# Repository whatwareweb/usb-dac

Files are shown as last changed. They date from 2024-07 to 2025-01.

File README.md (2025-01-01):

# usb-dac

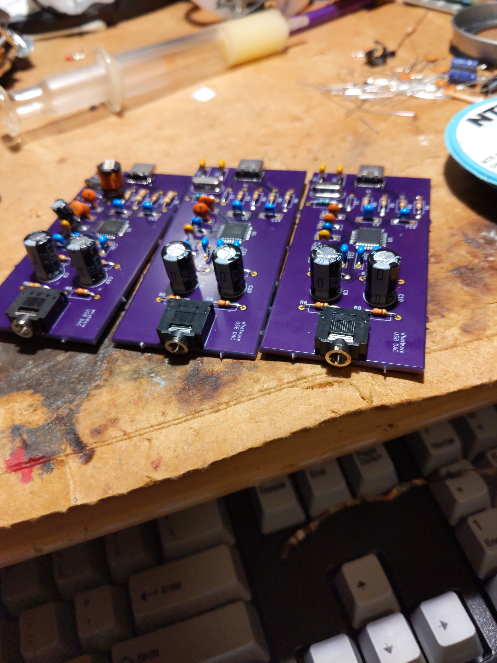
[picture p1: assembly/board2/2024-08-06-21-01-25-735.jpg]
photos of assembled boards


USB DAC based on TI PCM2912A IC

This design is tested and working, I use it as my daily driver DAC

## pcb fabrication
I ordered my pcbs from OSHpark, the project link is here for a 1-click order that is already configured and will work well https://oshpark.com/shared_projects/iy0FjLmS

## performance tweaking
This DAC has been designed with good low-frequency response in mind, large output capacitors are used to ensure very low frequencies can be reproduced

To adjust high-frequency response, C4 and C5 can be decreased to allow higher-frequency sounds to make it to the output. Too high of a capacitance for either of these will lead to a muffled sound

C9 and C10 are the output capacitors, the Rubycon model listed in the BOM does very well for the price but they can be swapped out for any higher quality electrolytic capacitor with the same lead spacing. to increase LF response make these a larger value, to decrease make them a smaller value. I just used these as I had like 70 of them spare from another project

## assembly
Check the assembly directory for assembly pictures

This board design is tested and working, but if you would like any help you can open a github issue and I'll try my best (no i will most likely not give you one for free, sorry)

During assembly it is very helpful to open the board view in KiCad to see the component values and the BOM

This board has been designed with easy assembly in mind, there are only 2 SMD parts which you could get assembled for you at a PCB assembly service, the rest of the parts are through-hole and very easy to solder DIY.

## parts
The parts in the BOM can all be purchased at Mouser electronics (DigiKey probably has them too, I didn't check)

I just went with the cheapest option of the rated component value with a minimum voltage rating of 5v, so if you need to get components from some other supplier you can do that as well and it will probably work, just make sure to double-check the lead spacing for the capacitors, inductors, etc

## bom
To export the BOM, open the schematic in Kicad, and click the BOM icon in the toolbar, from there you can copy/paste or export

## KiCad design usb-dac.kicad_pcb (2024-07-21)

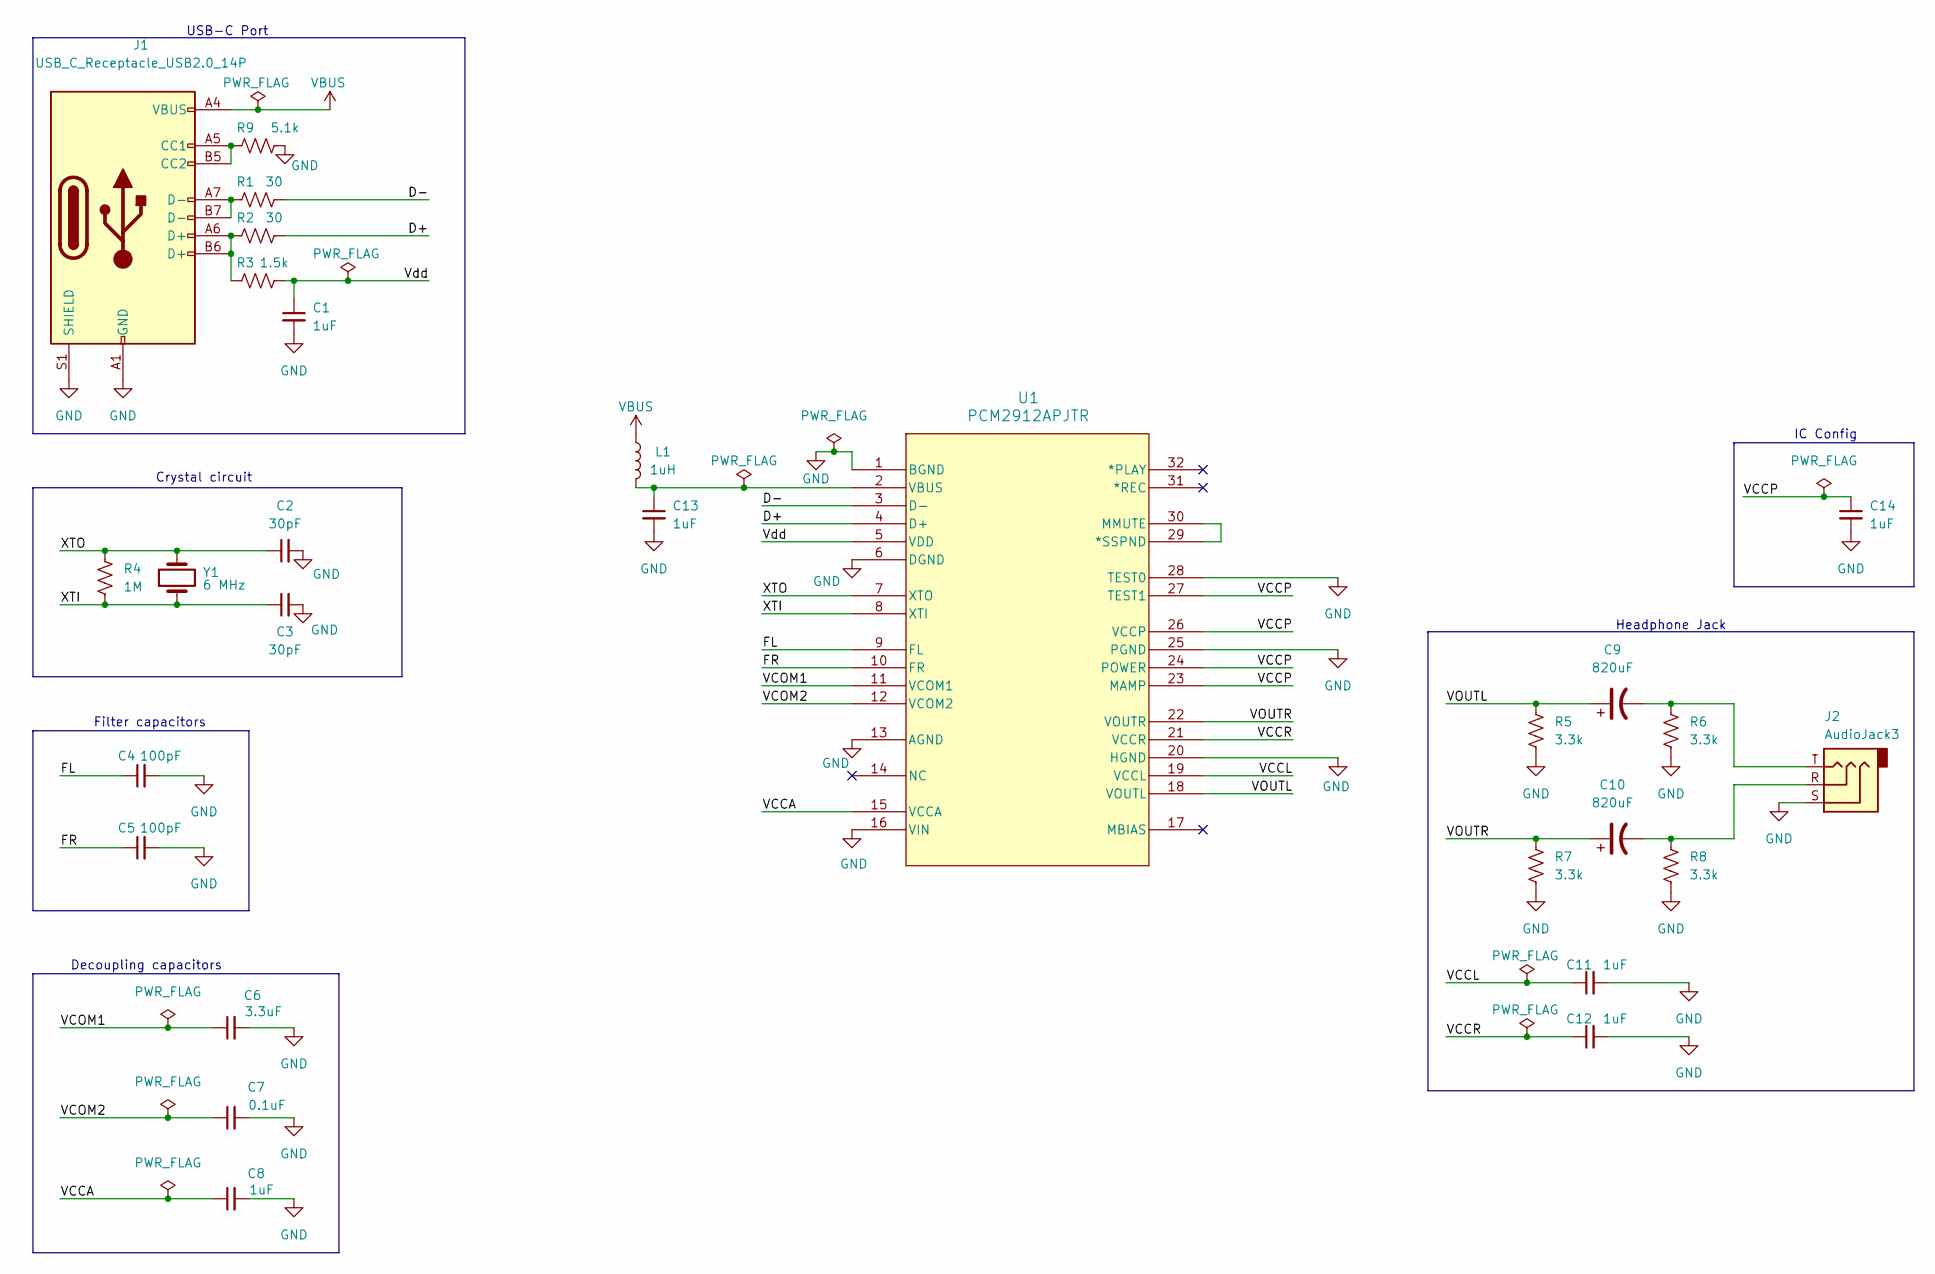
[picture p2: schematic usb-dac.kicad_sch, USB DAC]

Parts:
C1, C8, C11, C12, C13, C14: 1uF; C_Rect_L7.0mm_W2.0mm_P5.00mm; Mfr. # FG28X7R1E105KRT00
C2, C3: 30pF; C_Rect_L7.0mm_W2.0mm_P5.00mm; Mfr. # K300J10C0GF5UH5
C4, C5: 100pF; C_Rect_L7.0mm_W2.0mm_P5.00mm; Mfr. # XR501101K040HAND5P
C6: 3.3uF; C_Rect_L7.0mm_W2.0mm_P5.00mm; Mfr. # FA24X7R1E335KRU06
C7: 0.1uF; C_Rect_L7.0mm_W2.0mm_P5.00mm; Mfr. # K104K10X7RF5UH5
C9, C10: 820uF; CP_Radial_D8.0mm_P3.50mm; Mfr. # 6.3ZLH820MEFC8X11.5
J1: USB_C_Receptacle_USB2.0_14P; USB_C_Receptacle_GCT_USB4105-xx-A_16P_TopMnt_Horizontal; Mfr. # USB4085
J2: AudioJack3; Jack_3.5mm_CUI_SJ1-3523N_Horizontal; Mfr. # SJ1-3523N
L1: 1uH; L_Axial_L5.3mm_D2.2mm_P7.62mm_Horizontal_Vishay_IM-1; Mfr. # AICC-02-1R0M-T
R1, R2: 30; R_Axial_DIN0207_L6.3mm_D2.5mm_P10.16mm_Horizontal; Mfr. # CF14JT30R0
R3: 1.5k; R_Axial_DIN0207_L6.3mm_D2.5mm_P10.16mm_Horizontal; Mfr. # CFR-12JB-52-1K5
R4: 1M; R_Axial_DIN0207_L6.3mm_D2.5mm_P10.16mm_Horizontal; Mfr. # RNF18FTD1M00
R5, R6, R7, R8: 3.3k; R_Axial_DIN0207_L6.3mm_D2.5mm_P10.16mm_Horizontal; Mfr. # CFM14JT3K30
R9: 5.1k; R_Axial_DIN0207_L6.3mm_D2.5mm_P10.16mm_Horizontal; Mfr. # CF18JT5K10
U1: PCM2912APJTR; TQFP-32_7x7mm_P0.8mm; Mfr. # PCM2912APJTR
Y1: 6 MHz; Crystal_HC49-U_Vertical; Mfr. # ATS060

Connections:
/D+: R2.2, U1.4 (D+)
/D-: R1.2, U1.3 (D-)
/FL: C4.1, U1.9 (FL)
/FR: C5.1, U1.10 (FR)
/VCCA: C8.1, U1.15 (VCCA)
/VCCL: C11.1, U1.19 (VCCL)
/VCCP: C14.1, U1.23 (MAMP), U1.24 (POWER), U1.26 (VCCP), U1.27 (TEST1)
/VCCR: C12.1, U1.21 (VCCR)
/VCOM1: C6.1, U1.11 (VCOM1)
/VCOM2: C7.1, U1.12 (VCOM2)
/VOUTL: C9.1, R5.1, U1.18 (VOUTL)
/VOUTR: C10.1, R7.1, U1.22 (VOUTR)
/Vdd: C1.1, R3.2, U1.5 (VDD)
/XTI: C3.1, R4.2, U1.8 (XTI), Y1.1
/XTO: C2.1, R4.1, U1.7 (XTO), Y1.2
GND: C1.2, C2.2, C3.2, C4.2, C5.2, C6.2, C7.2, C8.2, C11.2, C12.2, C13.2, C14.2, J1.A1 (GND), J1.A12 (GND), J1.B1 (GND), J1.B12 (GND), J1.S1 (SHIELD), J2.S, R5.2, R6.2, R7.2, R8.2, R9.2, U1.1 (BGND), U1.6 (DGND), U1.13 (AGND), U1.16 (VIN), U1.20 (HGND), U1.25 (PGND), U1.28 (TEST0)
unnamed: C9.2, J2.T, R6.1
unnamed: C10.2, J2.R, R8.1
unnamed: J1.A5 (CC1), J1.B5 (CC2), R9.1
unnamed: J1.A6 (D+), J1.B6 (D+), R2.1, R3.1
unnamed: J1.A7 (D-), J1.B7 (D-), R1.1
unnamed: U1.29 (*SSPND), U1.30 (MMUTE)
unnamed: C13.1, L1.2, U1.2 (VBUS)
VBUS: J1.A4 (VBUS), J1.A9 (VBUS), J1.B4 (VBUS), J1.B9 (VBUS), L1.1

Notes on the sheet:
Filter capacitors
Headphone Jack
USB-C Port
Crystal circuit
Decoupling capacitors
IC Config

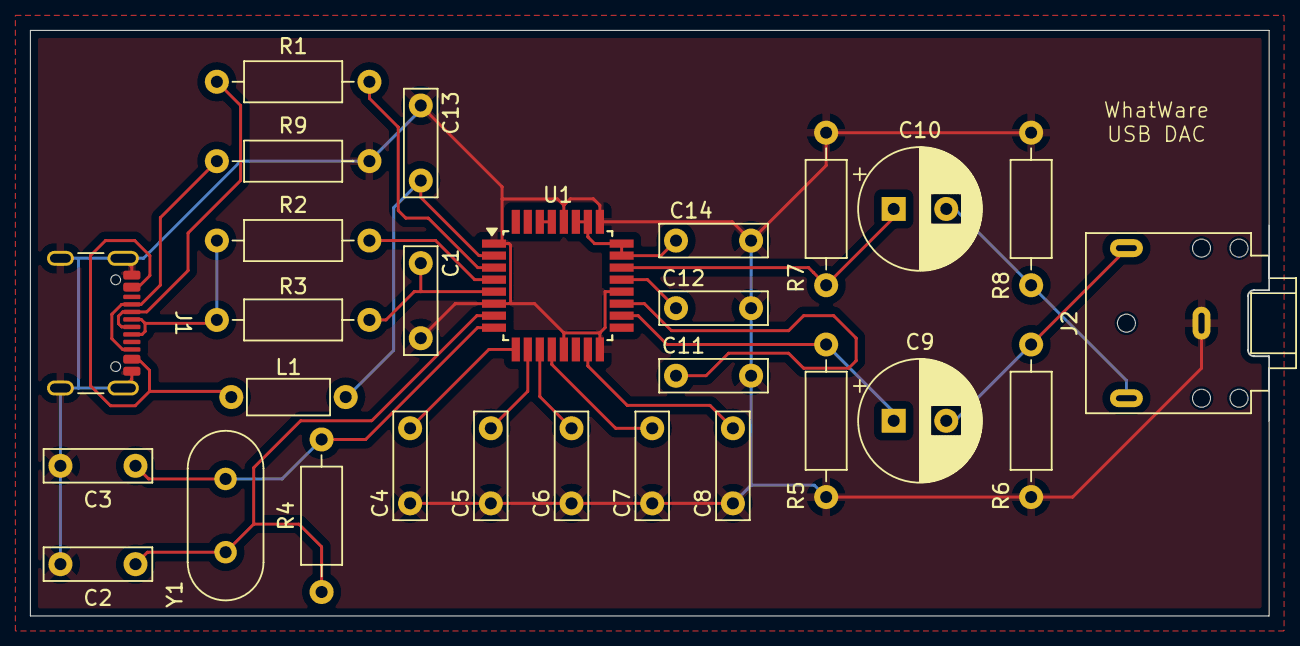
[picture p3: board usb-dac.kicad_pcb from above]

Board: 2 copper layers, 82.5 x 39.0 mm, 28 parts (0 on the bottom side), 24 nets.

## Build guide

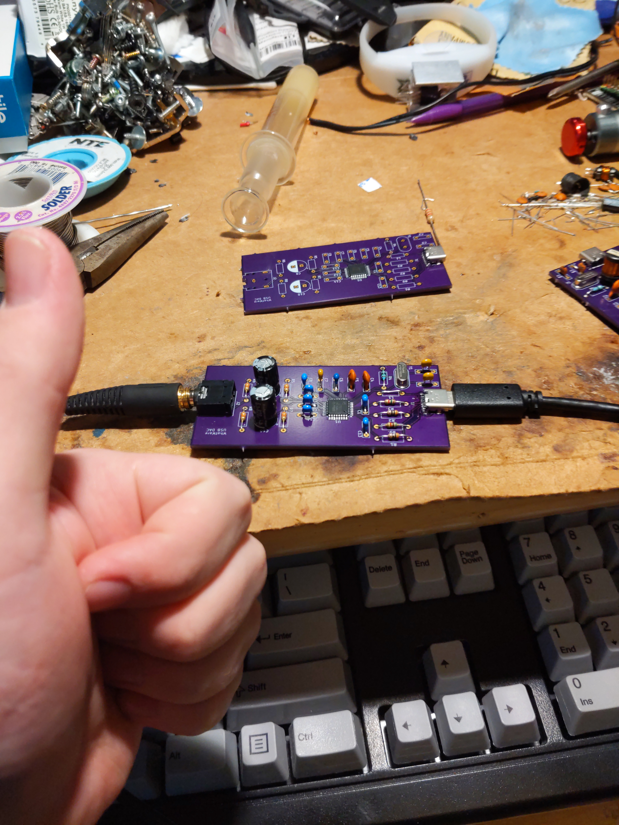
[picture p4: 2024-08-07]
assembly/board1/2024-08-06-19-01-29-325.jpg

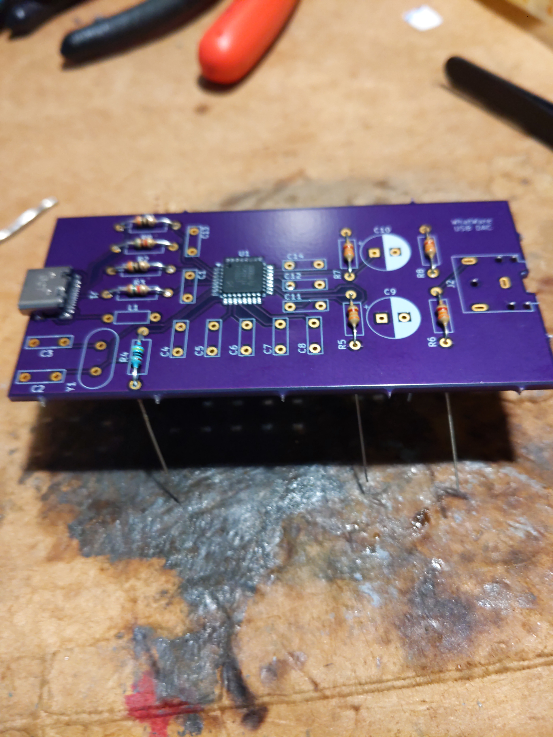
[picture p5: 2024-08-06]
assembly/board1/2024-08-06-17-47-50-258.jpg

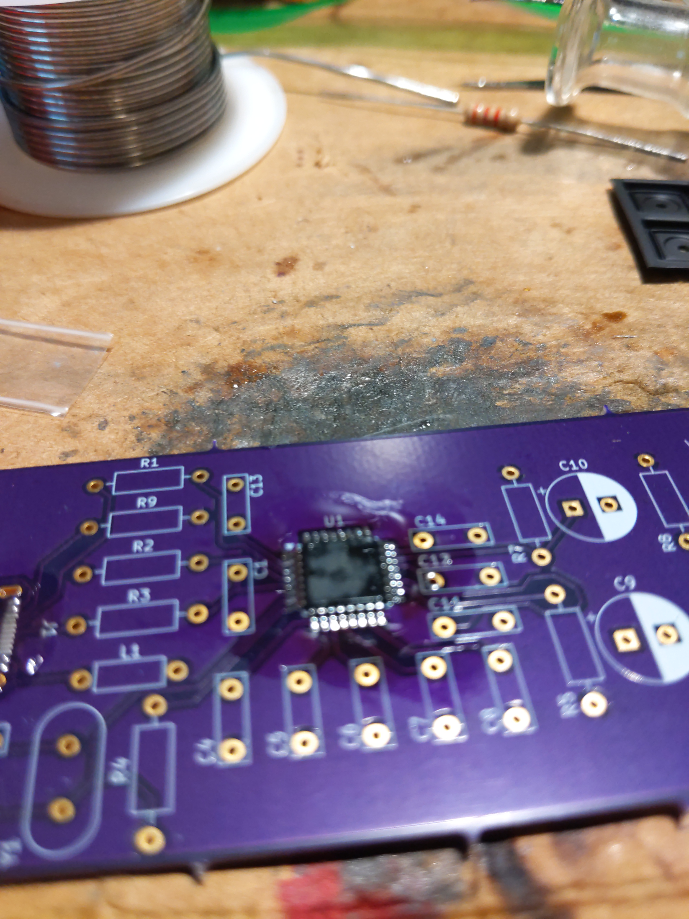
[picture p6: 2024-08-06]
assembly/board1/2024-08-06-16-56-17-795.jpg

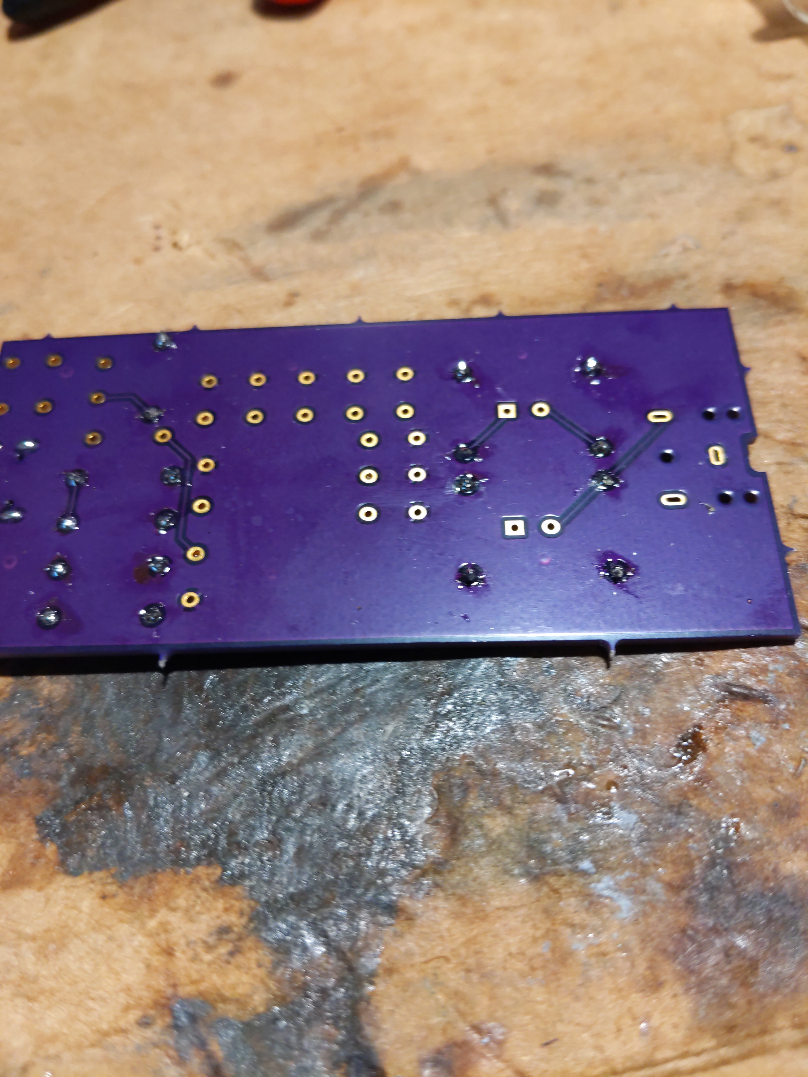
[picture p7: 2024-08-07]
assembly/board1/2024-08-06-17-56-30-761.jpg

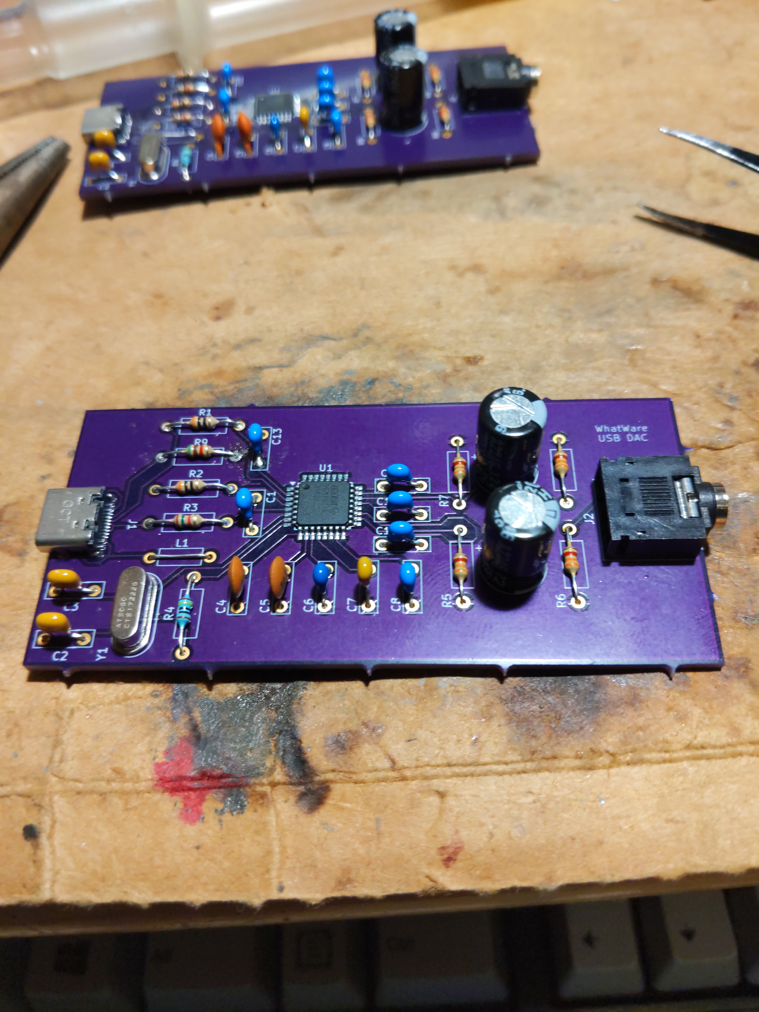
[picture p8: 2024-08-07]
assembly/board2/2024-08-06-20-35-10-456.jpg

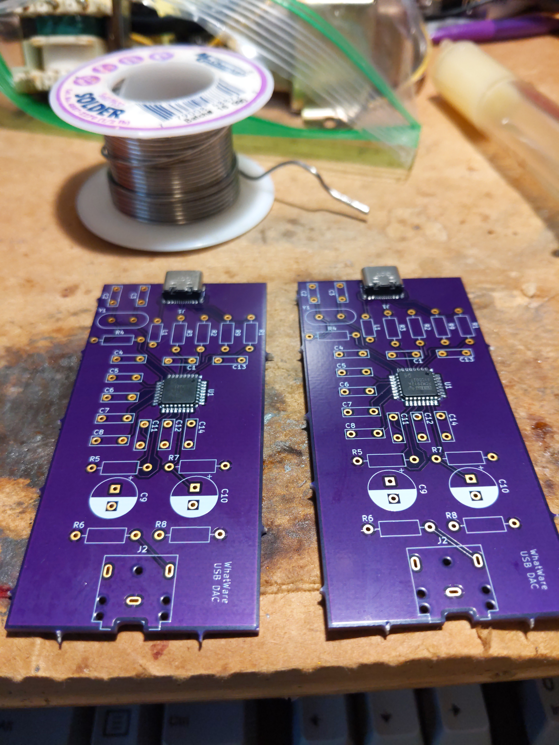
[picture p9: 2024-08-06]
assembly/board1/2024-08-06-17-20-58-425.jpg

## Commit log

2024-07-12 Add initial libraries and schematics
    [usb-dac.kicad_pcb, usb-dac.kicad_sch]
2024-07-12 Update schematic
    [usb-dac.kicad_sch]
2024-07-13 update schematic with new components
    [usb-dac.kicad_sch]
2024-07-13 Update schematic with separate chunks for different objects
    [usb-dac.kicad_sch]
2024-07-13 Work on schematic
    [usb-dac.kicad_sch]
2024-07-14 Some more work on the schematic
    [usb-dac.kicad_sch]
2024-07-15 More work on schematic Add headphone jack and reduce error amount
    [usb-dac.kicad_sch]
2024-07-15 Finish schematic
    [usb-dac.kicad_sch]
2024-07-16 Finished schematic
    [usb-dac.kicad_sch]
2024-07-16 Work on PCB
    [usb-dac.kicad_sch]
2024-07-17 Add more footprints
    [usb-dac.kicad_sch]
2024-07-18 BOM edits and footprint additions
    [usb-dac.kicad_sch]
2024-07-18 BOM and footprint work
    [usb-dac.kicad_sch]
2024-07-19 Start PCB placements
    [usb-dac.kicad_pcb, usb-dac.kicad_sch]
2024-07-20 Finish PCB and clarify schematic
    [usb-dac.kicad_pcb, usb-dac.kicad_sch]
2024-07-20 Update PCB with new schematic data
    [usb-dac.kicad_pcb]
2024-07-21 add "branding"
    [usb-dac.kicad_pcb]
2024-08-05 correct resistor and type-c port models
    [usb-dac.kicad_sch]
2024-08-06 Add a in-stock capacitor part
    [usb-dac.kicad_sch]
2024-08-06 add assembly images, SMD parts and resistors
2024-08-07 Add final assembly pictures
2024-08-07 add board2 assembly
2024-08-21 update readme with bom info
